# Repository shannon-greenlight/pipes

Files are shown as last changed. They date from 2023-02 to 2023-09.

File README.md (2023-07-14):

# Pipes - 8 Harmonic Tracking Oscillator with 8 VCAs
Pipes is a 14HP Eurorack module designed and made by Greenface Labs.
Used in conjunction with a VCO and an 8 output CV generating module such as the Bonkulator, Pipes is a great way to set the amplitude envelopes of a tone and 7 of its harmonics. The harmonics are 1f, 2f, 3f, 4f, 5f, 6f, 7f and 8f. They are generated as square waves.
Pipes features one signal input, a signal output, an output level adjustment pot, and eight CV inputs to the VCAs.
The signal input level must be greater than .1Vp-p for the phase-locked loop circuits to be able to lock on.
The output signal ranges from 0 to 10Vp-p. The CV inputs range is 0 - 10V.

These repos contain the materials needed to construct the Pipes main board and the front panel. The files are for KiCAD 6.0. 
Go to the Greenlight Kicad repo to get the needed libraries. The gerber files work with JLCPC and will most likely work with other board manufacturers.

When using the JLCPCB assembly service, the BOM is split into 3 parts.
- bom/lcsc/pipes_bom.xlsx : The parts to be assembled by JLCPCB
- bom/digi-key/pipes_bom.xlsx : The remaining parts to be assembled by user
- bom/other/other_bom.xlsx : The parts that must be bought from sources other than JLCPCB and Digi-Key

Also, when an assembly service is used, a component position file is required. This file's path is: fab/pipes_cpl.xlsx

notes: 	The cpl files are auto-generated from the .pos files produced by KiCAD. The bom files are generated by generate_boms.bat. You will need to refresh the data and save the file when changes to 
the schematic that affect the BOM or changes to the board layout occur. 
If they exist, the extra parts and additional data fields that appear on the schematic help to produce the different BOM files. 
They must be maintained for these BOMs to come out right.

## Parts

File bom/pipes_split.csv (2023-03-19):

Reference | Quantity | Value | Digi-Key Part #
J1, J4, J5, J6, J7, J8, J9, J10, J11, J12, J13, J14, J15, J16, J17, J18, J19, J20, | 18 | 3.5mm Jack | WM17366-ND
J3, | 1 | Eurorack Power Cable | H3CCS-1618G-ND
KN1, | 1 | CV Knob | 1722-1238-ND
N1, N2, N3, N4, | 4 | Nut | 36-4687-ND
RV1, | 1 | 1K | PTV09A-4225F-B102-ND
SC1, SC3, SC5, SC7, | 4 | Nylon Screw | 36-29331-ND
SC2, SC4, SC6, SC8, | 4 | Mounting Screw | 335-1156-ND
SO1, SO2, SO3, SO4, | 4 | Standoff 12mm | 732-13063-ND
SO5, SO6, SO7, SO8, | 4 | Standoff 15mm | 732-13072-ND
TP1, TP2, | 2 | TestPoint | 36-5006-ND
J1, | 1 | 2x8 Header | 732-5385-1-ND
J4, | 1 | 2x5 Header | 732-5382-1-ND
TP1, TP2, | 2 | TestPoint | 36-5006-ND

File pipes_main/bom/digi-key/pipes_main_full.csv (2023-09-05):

Reference | Quantity | Value | Digi-Key Part #
C1, C3, C5, C6, C7, C8, C9, C10, C29, C30, C31, C32, C33, C34, C35, C36, C39, C40, C41, C42, C43, C44, C45, C70, C71, C72, C73, C74, C75, C76, C77, C78, C79, C80, | 34 | 100nF | 478-10836-1-ND
C2, C17, C18, C23, C24, C25, C37, C38, | 8 | 10uF | 478-10836-1-ND
C4, C12, | 2 | 22uF | 478-12960-1-ND
C11, C13, C21, | 3 | 1nF | BC2662CT-ND
C14, | 1 | 470pF | BC2662CT-ND
C15, C20, C28, | 3 | 680pF | BC2662CT-ND
C16, | 1 | 4.7uF | 399-9877-1-ND
C19, C26, | 2 | 100pF | 399-9877-1-ND
C22, C27, | 2 | 300pF | BC2662CT-ND
C46, | 1 | 10pF | 399-9877-1-ND
D1, D2, D3, D4, D6, D7, D8, D9, D10, D11, D12, D13, D14, D15, D16, D17, D18, D19, D20, D21, D22, D23, D24, D25, D26, D27, D28, D29, D30, D31, D32, D33, D34, D35, | 34 | 1N5819 | 478-7800-1-ND
D5, | 1 | 1N4148 | 1N4148VSCT-ND
J1, J4, J5, J6, J7, J8, J9, J10, J11, J12, J13, J14, J15, J16, J17, J18, J19, J20, | 18 | 3.5mm Jack | WM17366-ND
J3, | 1 | Eurorack Power Cable | H3CCS-1618G-ND
J21, | 1 | 2x8 Female Header | H3CCS-1618G-ND
J22, | 1 | 2x5 Female Header | S2011EC-05-ND
KN1, | 1 | CV Knob | 1722-1238-ND
N1, N2, N3, N4, | 4 | Nut | 36-4687-ND
R1, R8, | 2 | 68K | CF14JT10K0CT-ND
R2, R6, R12, R13, R14, R15, R16, R17, R20, R21, R29, R30, R31, R38, R39, R44, R45, | 17 | 10K | CRT0805-FZ-1002ELFCT-ND
R3, R5, | 2 | 100K | CF14JT10K0CT-ND
R4, R9, | 2 | 2K | CRT0805-FZ-1002ELFCT-ND
R7, | 1 | 200K | CF14JT10K0CT-ND
R10, | 1 | 133K | CRT0805-FZ-1002ELFCT-ND
R11, | 1 | 475K | CRT0805-FZ-1002ELFCT-ND
R18, | 1 | 143K | CRT0805-FZ-1002ELFCT-ND
R19, R22, R27, R28, R71, R72, R73, R74, R75, R78, R79, R80, R81, R82, R83, R84, R85, | 17 | 510 | CRT0805-FZ-1002ELFCT-ND
R23, R25, R32, R34, R36, R40, R42, | 7 | 27K | CF14JT10K0CT-ND
R24, R26, R33, R35, R37, R41, R43, | 7 | 1.5K | CF14JT10K0CT-ND
R68, | 1 | 4.42K | CRT0805-FZ-1002ELFCT-ND
R69, | 1 | 3.83K | CF14JT68K0CT-ND
R70, | 1 | 620 | CF14JT68K0CT-ND
RV1, | 1 | 1K | PTV09A-4225F-B102-ND
RV10, RV11, RV13, RV14, RV15, RV16, RV17, | 7 | 50K | 490-2881-ND
SC1, SC3, SC5, SC7, | 4 | Nylon Screw | 36-29331-ND
SC2, SC4, SC6, SC8, | 4 | Mounting Screw | 335-1156-ND
SO1, SO2, SO3, SO4, | 4 | Standoff 12mm | 732-13063-ND
SO5, SO6, SO7, SO8, | 4 | Standoff 15mm | 732-13072-ND
TP1, TP2, | 2 | TestPoint | 36-5006-ND
U1, U2, | 2 | TL072CP | 296-1775-5-ND
U7, U8, U13, U14, U15, U18, U19, | 7 | CD4017 | 296-12808-1-ND
U36, U37, U38, U39, | 4 | CD40107 | 296-31481-1-ND

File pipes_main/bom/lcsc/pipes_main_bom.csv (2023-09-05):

Designator | Comment | Footprint | JLCPCBPart#
C1, C3, C5, C6, C7, C8, C9, C10, C29, C30, C31, C32, C33, C34, C35, C36, C39, C40, C41, C42, C43, C44, C45, C70, C71, C72, C73, C74, C75, C76, C77, C78, C79, C80, | 100nF | Capacitor_SMD:C_0805_2012Metric_Pad1.18x1.45mm_HandSolder | C49678
C2, C17, C18, C23, C24, C25, C37, C38, | 10uF | Capacitor_SMD:C_0805_2012Metric_Pad1.18x1.45mm_HandSolder | C15850
C4, C12, | 22uF | Capacitor_Tantalum_SMD:CP_EIA-3216-18_Kemet-A | C129272
C11, C13, C21, | 1nF | Capacitor_SMD:C_0805_2012Metric_Pad1.18x1.45mm_HandSolder | C46653
C14, | 470pF | Capacitor_SMD:C_0805_2012Metric_Pad1.18x1.45mm_HandSolder | C1743
C15, C20, C28, | 680pF | Capacitor_SMD:C_0805_2012Metric_Pad1.18x1.45mm_HandSolder | C520092
C16, | 4.7uF | Capacitor_SMD:C_1206_3216Metric | C29823
C19, C26, | 100pF | Capacitor_SMD:C_0805_2012Metric_Pad1.18x1.45mm_HandSolder | C1790
C22, C27, | 300pF | Capacitor_SMD:C_0805_2012Metric_Pad1.18x1.45mm_HandSolder | C282698
C46, | 10pF | Capacitor_SMD:C_0805_2012Metric_Pad1.18x1.45mm_HandSolder | C107107
D1, D2, D3, D4, D6, D7, D8, D9, D10, D11, D12, D13, D14, D15, D16, D17, D18, D19, D20, D21, D22, D23, D24, D25, D26, D27, D28, D29, D30, D31, D32, D33, D34, D35, | 1N5819 | Diode_SMD:D_0805_2012Metric_Pad1.15x1.40mm_HandSolder | C191023
D5, | 1N4148 | Diode_SMD:D_SOD-123 | C2892570
J21, | 2x8 Female Header | sputterizer:PinSocket_2x08_P2.54mm_Vertical_SMD_guides | C3975153
J22, | 2x5 Female Header | sputterizer:PinSocket_2x05_P2.54mm_Vertical_SMD_guides | C3975150
Q1, Q2, | MMBT3904 | Package_TO_SOT_SMD:SOT-23 | C20526
R1, R8, | 68K | Resistor_SMD:R_0805_2012Metric_Pad1.20x1.40mm_HandSolder | C17801
R2, R6, R12, R13, R14, R15, R16, R17, R20, R21, R29, R30, R31, R38, R39, R44, R45, | 10K | Resistor_SMD:R_0603_1608Metric | C25804
R3, R5, | 100K | Resistor_SMD:R_0805_2012Metric_Pad1.20x1.40mm_HandSolder | C149504
R4, R9, | 2K | Resistor_SMD:R_0603_1608Metric | C22975
R7, | 200K | Resistor_SMD:R_0805_2012Metric_Pad1.20x1.40mm_HandSolder | C17539
R10, | 133K | Resistor_SMD:R_0603_1608Metric | C321714
R11, | 475K | Resistor_SMD:R_0603_1608Metric | C403244
R18, | 143K | Resistor_SMD:R_0603_1608Metric | C304703
R19, R22, R27, R28, R71, R72, R73, R74, R75, R78, R79, R80, R81, R82, R83, R84, R85, | 510 | Resistor_SMD:R_0805_2012Metric_Pad1.20x1.40mm_HandSolder | C2842425
R23, R25, R32, R34, R36, R40, R42, | 27K | Resistor_SMD:R_0805_2012Metric_Pad1.20x1.40mm_HandSolder | C17593
R24, R26, R33, R35, R37, R41, R43, | 1.5K | Resistor_SMD:R_0805_2012Metric_Pad1.20x1.40mm_HandSolder | C4310
R68, | 4.42K | Resistor_SMD:R_0603_1608Metric | C23043
R69, | 3.83K | Resistor_SMD:R_0805_2012Metric_Pad1.20x1.40mm_HandSolder | C483108
R70, | 620 | Resistor_SMD:R_0805_2012Metric_Pad1.20x1.40mm_HandSolder | C144551
RV10, RV11, RV13, RV14, RV15, RV16, RV17, | 50K | sputterizer:Potentiometer_Bourns_3224W_Vertical | C48484
U1, U2, | TL072CP | Package_SO:SOIC-8_3.9x4.9mm_P1.27mm | C67473
U3, | LM317_SOT-223 | Package_TO_SOT_SMD:SOT-223-3_TabPin2 | C347367
U4, U5, U10, U11, U12, U16, U17, | CD4046 | Package_SO:TSSOP-16_4.4x5mm_P0.65mm | C2651240
U6, | AMS1117-5.0 | Package_TO_SOT_SMD:SOT-223-3_TabPin2 | C6187
U7, U8, U13, U14, U15, U18, U19, | CD4017 | Package_SO:SOIC-16_3.9x9.9mm_P1.27mm | C11349
U36, U37, U38, U39, | CD40107 | Package_SO:SOIC-8_3.9x4.9mm_P1.27mm | C2691402

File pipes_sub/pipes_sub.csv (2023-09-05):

Reference | Quantity | Value | Footprint | Datasheet | Digi-Key Part | LCSC Part #
C1 C14 C15 C20 C21 C22 C27 C28 | 8 | 300p | Capacitor_SMD:C_0805_2012Metric_Pad1.18x1.45mm_HandSolder | http://datasheets.avx.com/SR-Series.pdf | BC2662CT-ND | C282698
C2 C17 C18 C23 C24 C25 C37 C38 | 8 | 10uF | Capacitor_SMD:C_0805_2012Metric_Pad1.18x1.45mm_HandSolder | http://datasheets.avx.com/SR-Series.pdf | 478-10836-1-ND | C15850
C3 C70 C71 C72 C73 C74 C75 C76 | 8 | 30p | Capacitor_SMD:C_0805_2012Metric_Pad1.18x1.45mm_HandSolder | http://datasheets.avx.com/SR-Series.pdf | BC2662CT-ND | C107114
C4 C29 | 2 | 100uF | Capacitor_SMD:CP_Elec_6.3x5.4_Nichicon | http://www.rubycon.co.jp/en/catalog/e_pdfs/aluminum/e_ml.pdf | 399-EDH107M016A9GAACT-ND | C2887272
C46 C47 C48 C49 C50 C51 C52 C53 | 8 | 22uF | Capacitor_SMD:C_0805_2012Metric_Pad1.18x1.45mm_HandSolder | http://datasheets.avx.com/SR-Series.pdf | 478-10836-1-ND | C277470
C5 C6 C7 C8 C9 C10 C11 C12 C13 C16 C19 C26 C30 C31 C32 C33 C34 C35 C36 C39 C40 C41 C42 C43 C44 C45 C54 C55 C56 C57 C58 C59 C60 C61 C62 C63 C64 C65 C66 C67 C68 C69 | 42 | 100nF | Capacitor_SMD:C_0805_2012Metric_Pad1.18x1.45mm_HandSolder | http://datasheets.avx.com/SR-Series.pdf | 478-10836-1-ND | C49678
D1 D2 | 2 | 1N5819 | Diode_SMD:D_SOD-323_HandSoldering |  | 478-7800-1-ND | C191023
J1 | 1 | 2x8 Header | Connector_PinHeader_2.54mm:PinHeader_2x08_P2.54mm_Vertical_SMD |  | 732-5385-1-ND
J2 J4 | 2 | 2x5 Header | Connector_PinHeader_2.54mm:PinHeader_2x05_P2.54mm_Vertical_SMD |  |  | C124391
R1 R3 R10 R11 R12 R13 R14 R15 R16 R17 R20 R21 R29 R30 R31 R38 R39 R139 R140 | 19 | 10K | Resistor_SMD:R_0603_1608Metric |  | CRT0805-FZ-1002ELFCT-ND | C25804
R141 R142 R145 R146 R149 R150 R153 R154 | 8 | 237K | Resistor_SMD:R_0603_1608Metric |  | CF14JT10K0CT-ND | C403089
R143 R144 R147 R148 R151 R152 R155 R156 | 8 | 191K | Resistor_SMD:R_0603_1608Metric |  | CF14JT10K0CT-ND | C861179
R2 R71 R76 R91 R96 R111 R116 R131 R136 R157 R158 R159 R160 R161 R162 R163 R164 R165 R166 R167 R168 R169 R170 R171 | 24 | 200K | Resistor_SMD:R_0603_1608Metric |  | CF14JT10K0CT-ND | C25811
R28 R72 R87 R92 R107 R112 R127 R132 | 8 | 150K | Resistor_SMD:R_0603_1608Metric |  | CF14JT10K0CT-ND | C22807
R4 R23 R25 R32 R34 R36 R40 R42 | 8 | 27K | Resistor_SMD:R_0805_2012Metric_Pad1.20x1.40mm_HandSolder |  | CF14JT10K0CT-ND | C17593
R45 R47 R49 R54 R56 R58 R63 R65 | 8 | 20K | Resistor_SMD:R_0603_1608Metric |  | CRT0805-FZ-1002ELFCT-ND | C136589
R5 R24 R26 R33 R35 R37 R41 R43 | 8 | 1.5K | Resistor_SMD:R_0805_2012Metric_Pad1.20x1.40mm_HandSolder |  | CF14JT10K0CT-ND | C4310
R50 R51 R52 R59 R60 R61 R66 R67 | 8 | 430 | Resistor_SMD:R_0603_1608Metric |  | CRT0805-FZ-1002ELFCT-ND | C23170
R6 R18 R79 R83 R99 R103 R119 R123 | 8 | 162K | Resistor_SMD:R_0603_1608Metric |  | CF14JT10K0CT-ND | C217756
R68 R73 R88 R93 R108 R113 R128 R133 | 8 | 174K | Resistor_SMD:R_0603_1608Metric |  | CF14JT10K0CT-ND | C2933159
R69 R74 R89 R94 R109 R114 R129 R134 | 8 | 261K | Resistor_SMD:R_0603_1608Metric |  | CF14JT10K0CT-ND | C2930083
R7 R19 R80 R84 R100 R104 R120 R124 | 8 | 154K | Resistor_SMD:R_0603_1608Metric |  | CF14JT10K0CT-ND | C321731
R70 R75 R90 R95 R110 R115 R130 R135 | 8 | 287K | Resistor_SMD:R_0603_1608Metric |  | CF14JT10K0CT-ND | C5159700
R77 R78 R97 R98 R117 R118 R137 R138 | 8 | 332K | Resistor_SMD:R_0603_1608Metric |  | CF14JT10K0CT-ND | C403165
R8 R22 R81 R85 R101 R105 R121 R125 | 8 | 210K | Resistor_SMD:R_0603_1608Metric |  | CF14JT10K0CT-ND | C227705
R9 R27 R82 R86 R102 R106 R122 R126 | 8 | 300K | Resistor_SMD:R_0603_1608Metric |  | CF14JT10K0CT-ND | C23024
RV1 RV10 RV11 RV13 RV14 RV15 RV16 RV17 | 8 | 50K | sputterizer:Potentiometer_Bourns_3224W_Vertical | https://www.bourns.com/docs/Product-Datasheets/TC33.pdf | 490-2881-ND | C48484
RV2 RV3 RV4 RV5 RV6 RV7 RV8 RV9 | 8 | 500 | Potentiometer_SMD:Potentiometer_Bourns_3224W_Vertical | https://www.bourns.com/docs/Product-Datasheets/TC33.pdf |  | C116324
TP1 TP2 | 2 | TestPoint | TestPoint:TestPoint_Keystone_5005-5009_Compact |  | 36-5006-ND | C5199801
U1 U4 U5 U10 U11 U12 U16 U17 | 8 | CD4046 | Package_SO:TSSOP-16_4.4x5mm_P0.65mm | https://assets.nexperia.com/documents/data-sheet/HEF4046B.pdf |  | C2651240
U2 U6 U9 U23 U24 U25 U29 U30 U31 U34 U35 U38 U39 | 13 | TL072CP | Package_SO:SOIC-8_3.9x4.9mm_P1.27mm |  | 296-1775-5-ND | C67473
U20 U21 U22 U26 U27 U28 U32 U33 | 8 | NSL-32SR3 | OptoDevice:PerkinElmer_VTL5C | http://www.qsl.net/wa1ion/vactrol/vactrol.pdf | NSL-32SR3-ND
U3 U7 U8 U13 U14 U15 U18 U19 | 8 | CD4017 | Package_SO:SOIC-16_3.9x9.9mm_P1.27mm | http://www.intersil.com/content/dam/Intersil/documents/cd40/cd4017bms-22bms.pdf | 296-12808-1-ND | C11349

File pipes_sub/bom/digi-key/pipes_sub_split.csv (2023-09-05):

Reference | Quantity | Value | Digi-Key Part #
J1, | 1 | 2x8 Header | 732-5385-1-ND
J4, | 1 | 2x5 Header | 732-5382-1-ND
U20, U21, U22, U26, U27, U28, U32, U33, | 8 | NSL-32SR3 | NSL-32SR3-ND

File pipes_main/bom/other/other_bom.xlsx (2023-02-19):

Reference | Quantity | Value | URL
M1 | 1 | OLED | https://www.amazon.com/gp/product/B072Q2X2LL/

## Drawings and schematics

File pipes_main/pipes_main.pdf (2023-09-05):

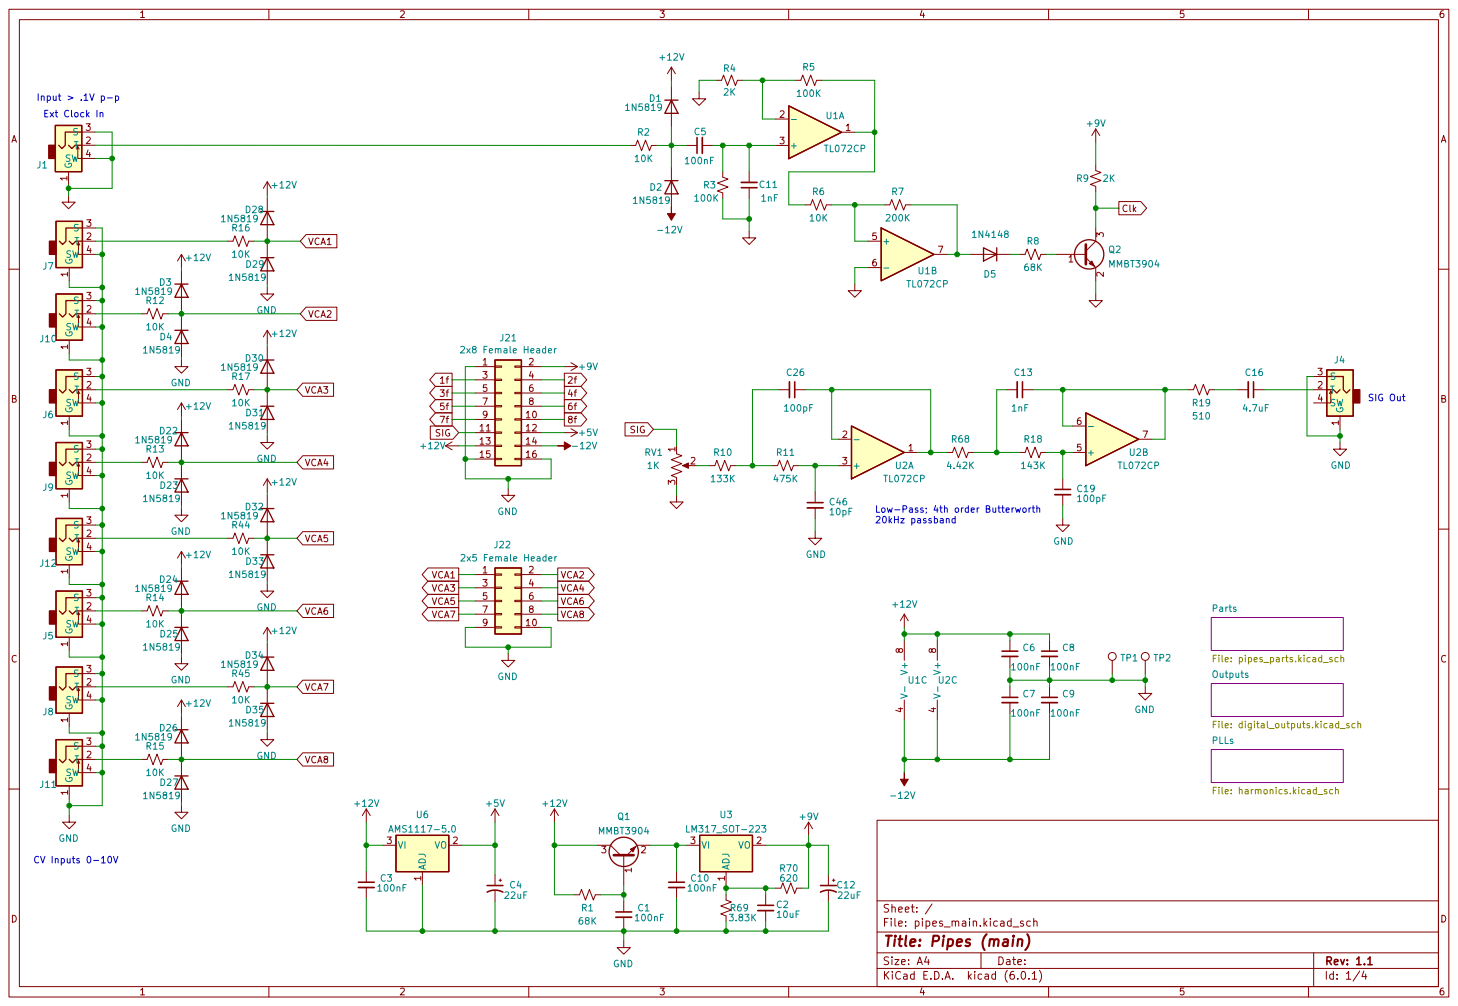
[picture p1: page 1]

Input > .1V p-p Ext Clock In

Low-Pass; 4th order Butterworth

Id: 1/4 Title: Pipes (main)

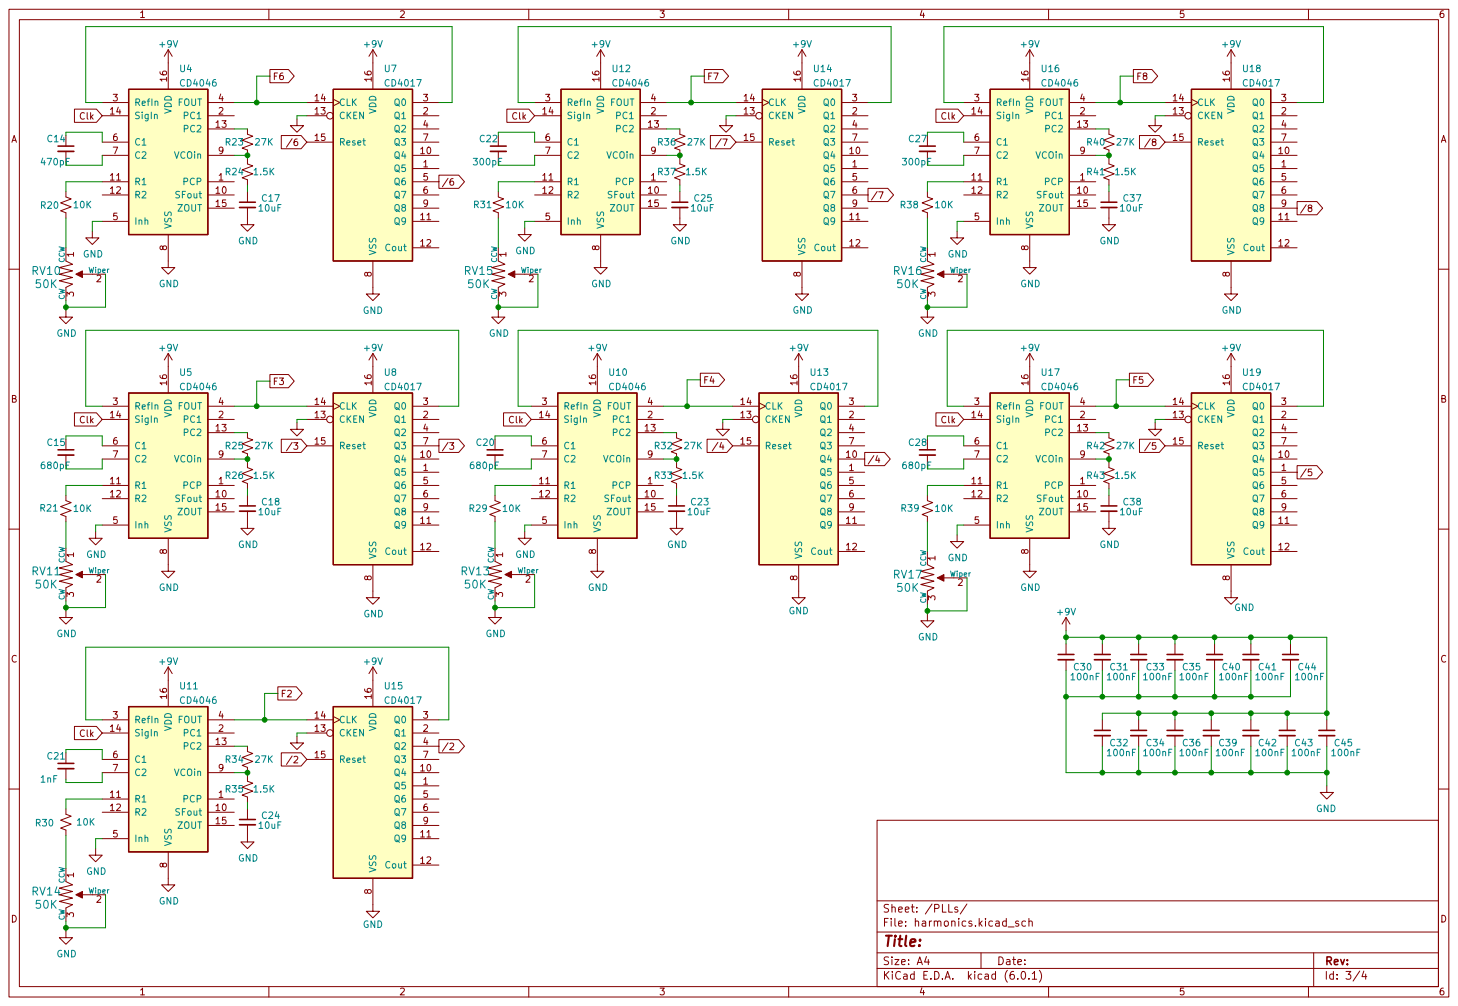
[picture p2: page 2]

8 VCOin 9 U12 CD4046 +9V +9V Q5 1 Q4 10 Q9 11 Cout 12 CKEN 13 CLK 14 Reset 15 VDD 16 Q1 2 Q0 3 Q2 4 Q6 5 Q7 6 Q3 7 VSS

8 Q8 9 U14 CD4017 Q5 1 Q4 10 Q9 11 Cout 12 CKEN 13 CLK 14 Reset 15 VDD 16 Q1 2 Q0 3 Q2 4 Q6 5 Q7 6 Q3 7 VSS

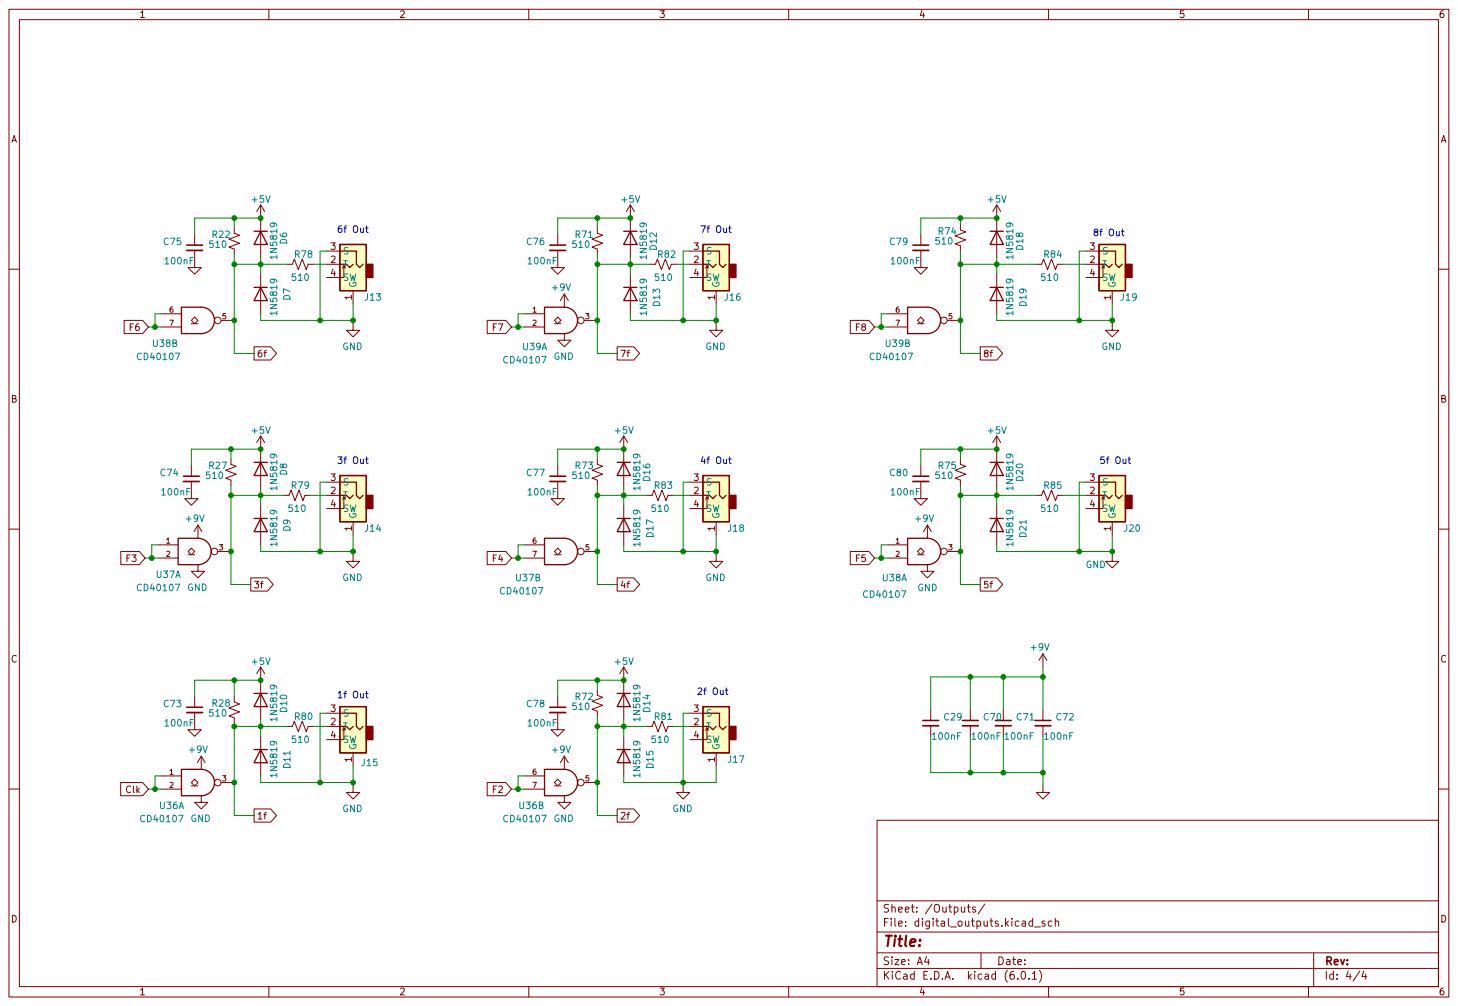
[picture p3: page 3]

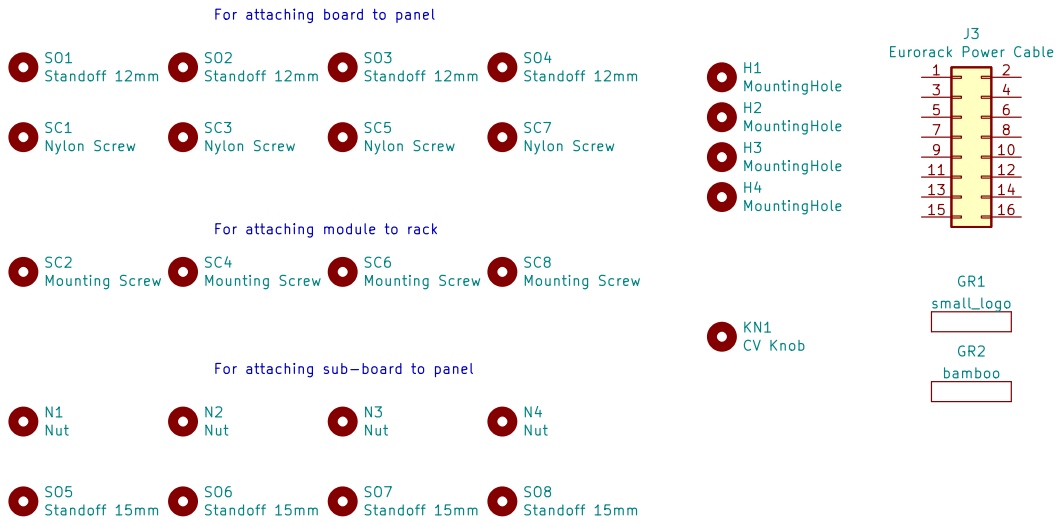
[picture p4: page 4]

For attaching board to panel

J3 Eurorack Power Cable SC8 Mounting Screw
SO4 Standoff 12mm

For attaching module to rack

For attaching sub-board to panel

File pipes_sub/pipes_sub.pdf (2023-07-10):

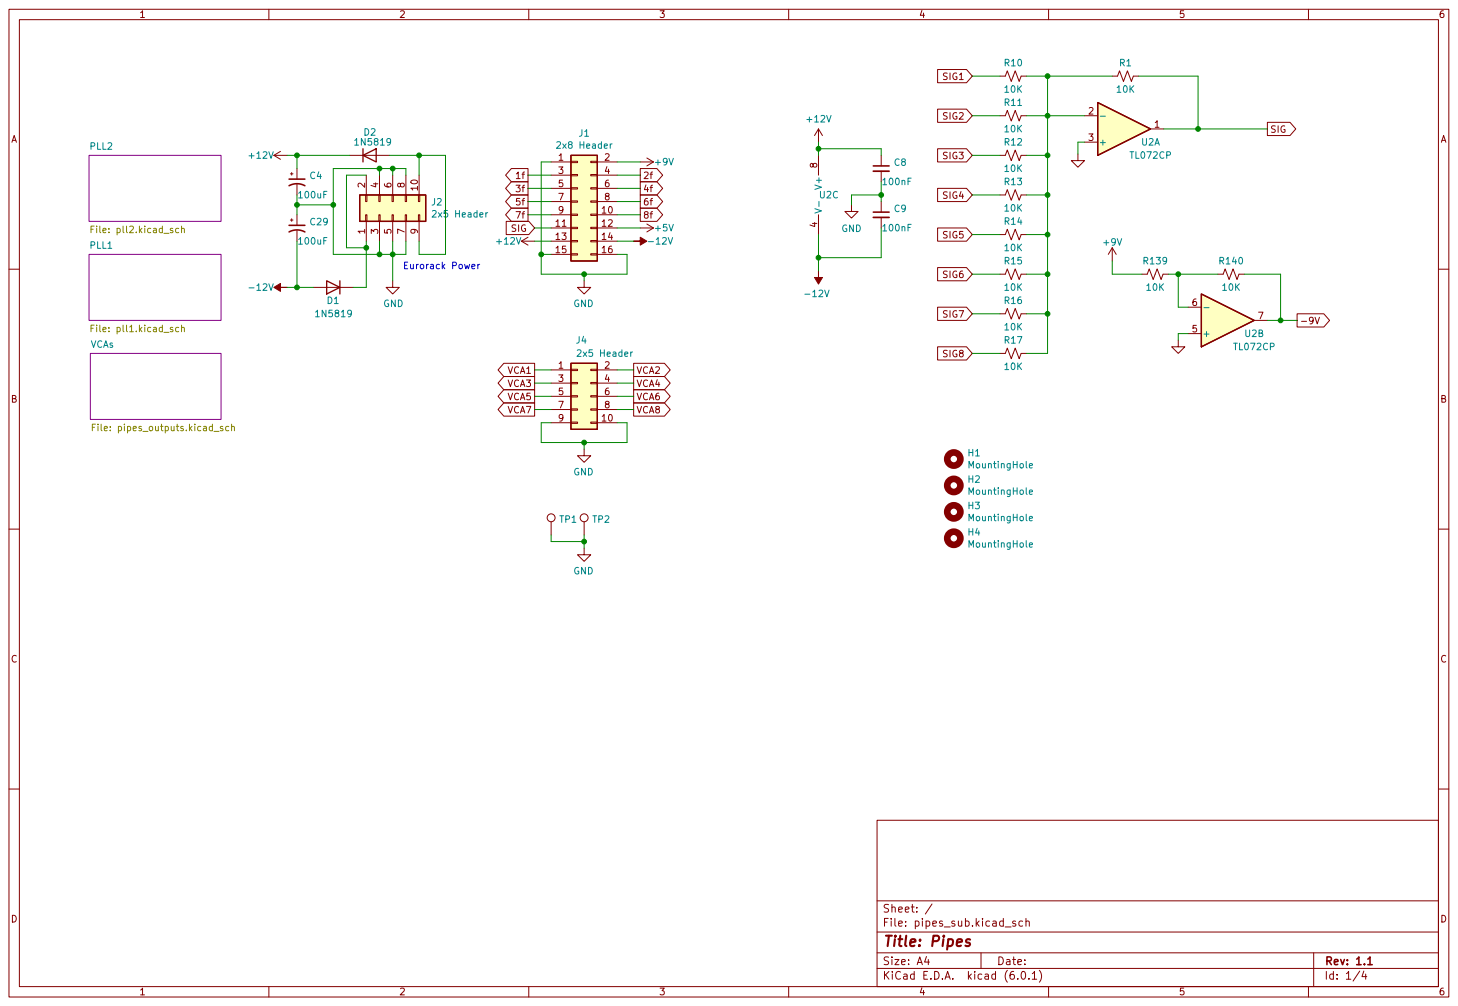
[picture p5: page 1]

PLL1 File: pll1.kicad_sch VCAs File: pipes_outputs.kicad_sch PLL2 File: pll2.kicad_sch

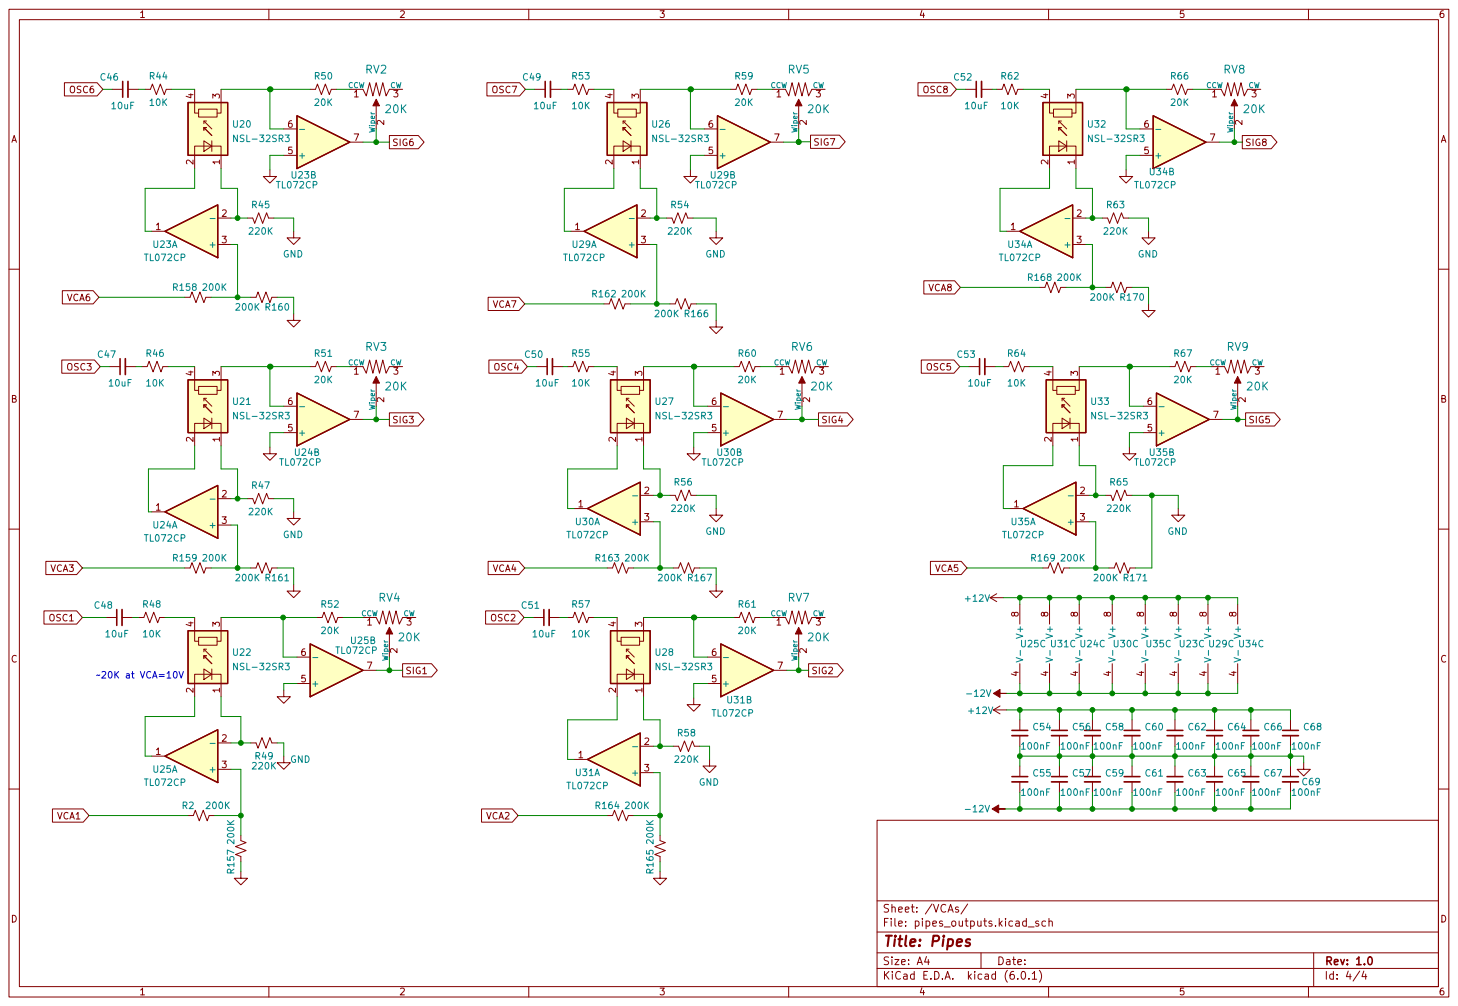
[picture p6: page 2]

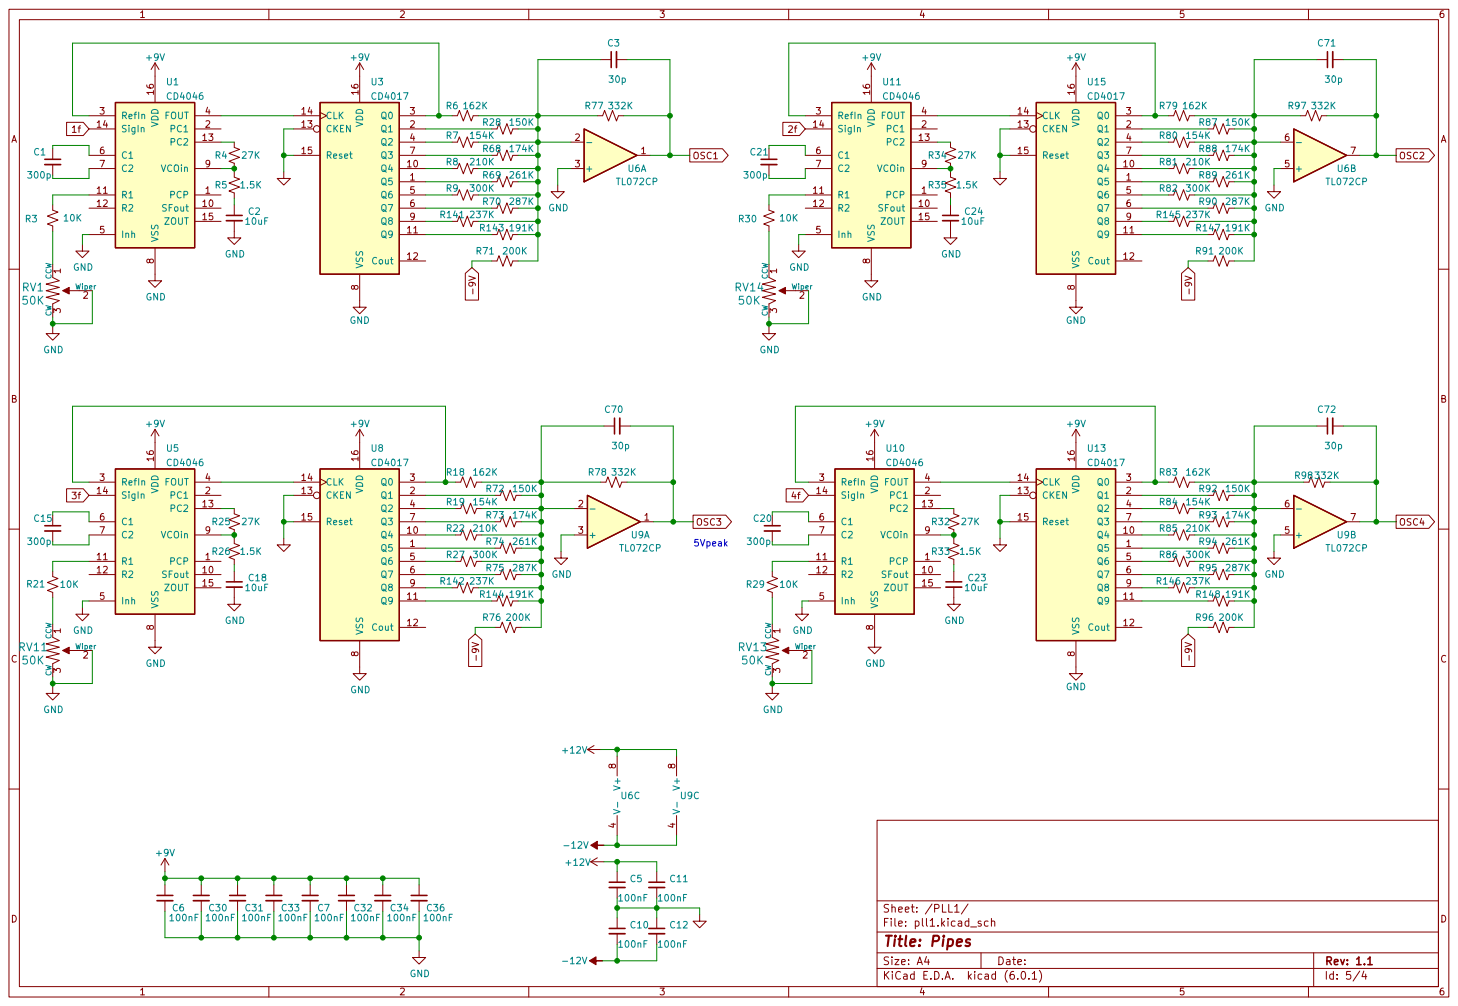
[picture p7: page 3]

8 VCOin 9 U11 CD4046 PCP 1 SFout 10 R1 11 R2 12 PC2 13 SigIn 14 ZOUT 15 VDD 16 PC1 2 RefIn 3 FOUT 4

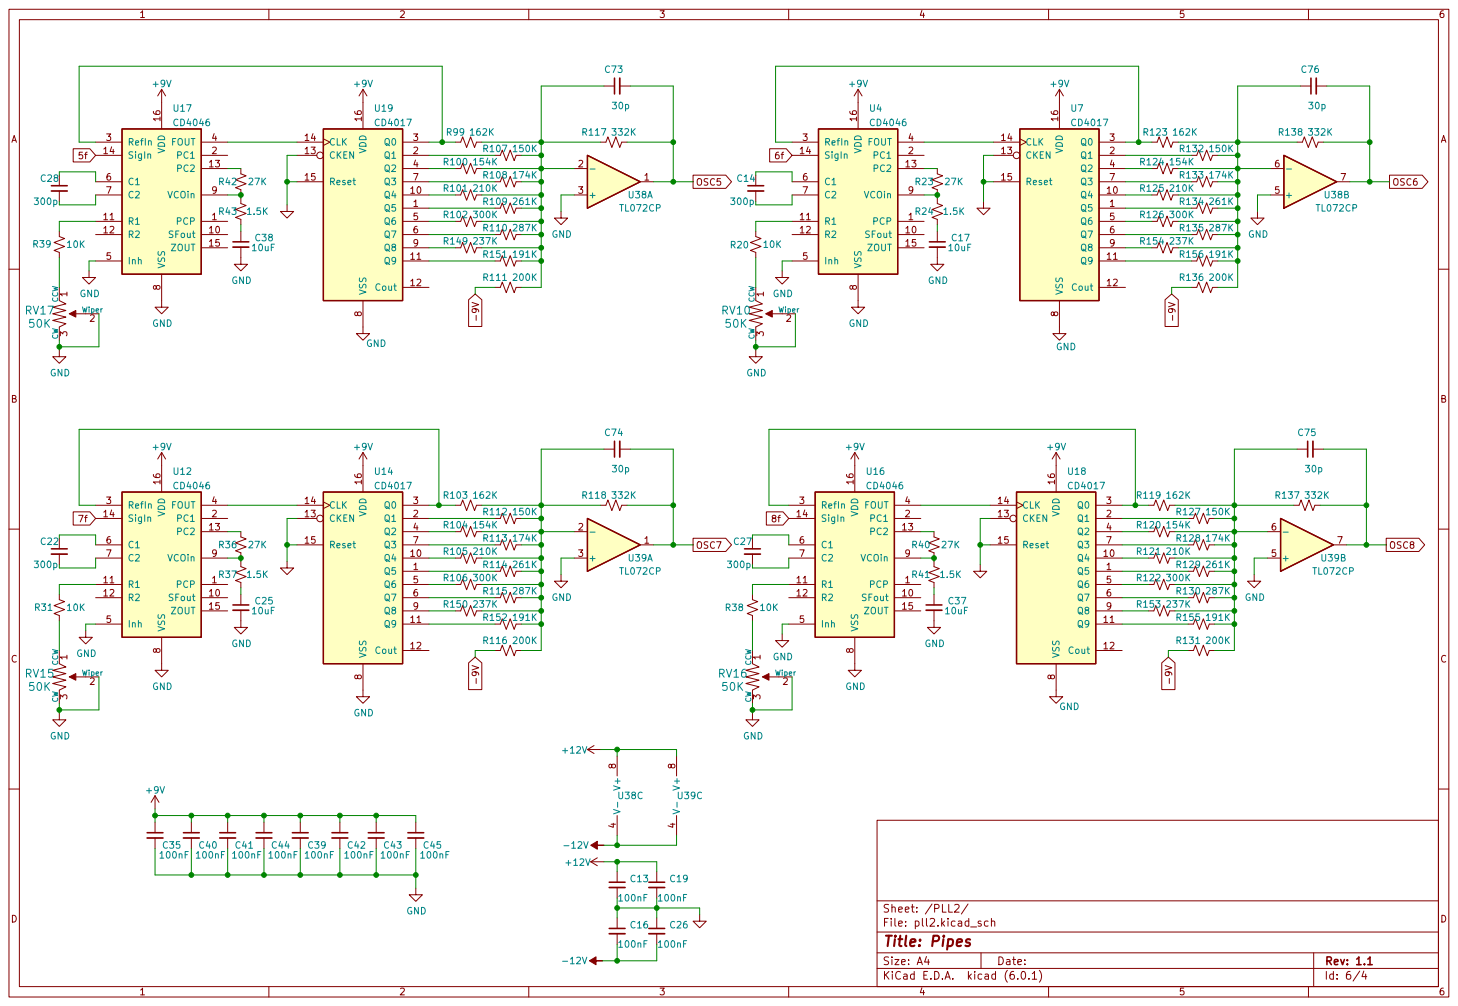
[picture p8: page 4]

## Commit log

2023-02-19 Init checkin
    [harmonics.kicad_sch, other_bom.xlsx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]
2023-02-19 Changes to use LM317
    [pipes-B_Cu.gbr, pipes-B_Mask.gbr, pipes-B_Paste.gbr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]
2023-03-01 Adds harmonic outputs
    [digital_outputs.kicad_sch, harmonics.kicad_sch, panel.kicad_pcb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]
2023-03-06 Next gen. Adds sine wave generators.
    [digital_outputs.kicad_sch, harmonics.kicad_sch, other_bom.xlsx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]
2023-03-06 Updates pipes_sub. Gerbers, schematic, reports.
    [pipes_cpl.xlsx, pipes_sub-B_Cu.gbr, pipes_sub-B_Mask.gbr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]
2023-03-07 Adds block diagram
    [pipes_block_diagram.kicad_pcb, pipes_block_diagram.kicad_sch]
2023-03-07 Swaps bamboo silkscreen for face logo.
    [pipes_main.kicad_pcb, pipes_main.kicad_sch, pipes_parts.kicad_sch]
2023-03-07 File cleanup
    [digital_outputs.kicad_sch, harmonics.kicad_sch, other_bom.xlsx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]
2023-03-08 Changes labels: VCO to SIG
    [pipes_outputs.kicad_sch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]
2023-03-08 Changes label VCO to Analog
    [panel.kicad_pcb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]
2023-03-08 Updates component values. Uses .5W resistors on outputs now.
    [digital_outputs.kicad_sch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]
2023-03-19 Adds digikey bom merge. Uses local graphics for panel.
    Adds bambooh graphics
    [harmonics.kicad_sch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]
2023-07-09 Version 1.1 of boards
    Changes to use NSL-32SR3 Vactrols
    Fixes 3904 package
    Adds 10-step waveform
    [digital_outputs.kicad_sch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]
2023-07-10 Changed note on vactrol resistance.
    [pipes_outputs.kicad_sch]
2023-09-05 Uses new vactrols.
    [pipes_main-B_Cu.gbr, pipes_main-B_Mask.gbr, pipes_main-B_Paste.gbr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]
